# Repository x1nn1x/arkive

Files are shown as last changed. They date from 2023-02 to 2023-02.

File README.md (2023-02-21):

# Arkive v0.1 - 
Build your own Ark Dev Kit

A full Ark Dev Kit consists of a [screen](https://mou.sr/3QI0UAi), [battery](https://mou.sr/3QJygi1), [micro-sd card](https://mou.sr/3WlwoNI), [compute module](https://www.raspberrypi.com/products/compute-module-3-plus/), a case, and the Ark PCB both of which are available to be printed using this Arkive.

How To:

Upload one of these Gerber .zips to a PCB Manufacturer for them to print and deliver the PCBs needed you need to build an Ark Dev Kit. Print the case at home, or upload the files to a 3D printing service.

Notes:

Enabling touch screen

    Add Distro/pullup.dtbo to /boot/overlays
    Add Distro/touchscreen.dtbo to /boot/overlays
    Replace /home/pi/.bashrc with the Distro/.bashrc provided
    Make sure you are using the provided Distro/config.txt in /boot/

Enabling buttons

    Add Distro/buttons.dtbo to /boot/overlays
    Make sure you are using the provided Distro/config.txt in /boot/

Raspberry Pi Compute Module 3L+ (pending transition to CM4 and RISC-V): https://www.raspberrypi.com/products/compute-module-3-plus/

Newhaven Display 4.3" Capacitive Touch (pending transition to OLED and e-ink options]): [Mouser #: 763-4.3480272EFASXVC](https://mou.sr/3QI0UAi)

2500mAh LiPo battery: [Mouser #: 485-328](https://mou.sr/3QJygi1)

SD Card: [Mouser #: 467-SDSDQAD-128G](https://mou.sr/3WlwoNI)

Made with Love by Humans on Earth

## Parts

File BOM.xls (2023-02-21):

Sub-Assembly | Description | Part | Value | Package | Quantity | Link | Footprint Checked | Component
Pi Compute Module | SODIMM | A114854-ND | - | - | 1 | http://www.digikey.com/product-detail/en/te-connectivity-amp-connectors/1473149-4/A114854-ND/1890696 |  | U3
 | Resistor |  | 100k | 0402 | 5 | http://www.digikey.com/product-detail/en/panasonic-electronic-components/ERJ-2RKF1003X/P100KLCT-ND/194127 |  | R4, R5, R6, R7, R8
 | Capacitor |  | 4.7uF | 0603 | 2 | http://www.digikey.com/product-detail/en/samsung-electro-mechanics-america-inc/CL10B475KQ8NQNC/1276-2087-1-ND/3890173 |  | C2, C18
 | uSD Card Slot | WM6357CT-ND | - | - | 1 | http://www.digikey.com/product-detail/en/molex-llc/1040310811/WM6357CT-ND/2804769 |  | U4
 | Micro USB |  | - | - | 1 | http://www.digikey.com/product-detail/en/amphenol-fci/10103594-0001LF/609-4050-1-ND/2350357 |  | P2
Power Supplies | Fuse | MF-MSMF200-2CT-ND | 2A | - | 1 | http://www.digikey.com/product-detail/en/bourns-inc/MF-MSMF200-2/MF-MSMF200-2CT-ND/662850 |  | F1
 | Capacitor |  | 47uF | 1206 | 6 | http://www.digikey.com/product-detail/en/murata-electronics-north-america/GRM31CR60J476KE19L/490-6508-1-ND/3845705 |  | C1, C12, C14, C15, C16, C17
 | Capacitor |  | 100nF | 0402 | 2 | http://www.digikey.com/product-detail/en/kemet/C0402C104K9RACTU/399-4872-1-ND/1090867 |  | C5, C10
 | Capacitor |  | 10uF | 0805 | 4 | http://www.digikey.com/product-detail/en/murata-electronics-north-america/GRM219R60J106KE19D/490-3340-1-ND/702881 |  | C3, C4, C6, C7
 | Capacitor |  | 1uF | 0402 | 3 | http://www.digikey.com/product-detail/en/taiyo-yuden/JMK105BJ105KV-F/587-1231-1-ND/931008 |  | C9, C11, C13
 | Capacitor |  | 4.7uF | 0603 | 1 | http://www.digikey.com/product-detail/en/samsung-electro-mechanics-america-inc/CL10B475KQ8NQNC/1276-2087-1-ND/3890173 |  | C8
 | Resistor |  | 0R | 0402 | 2 | http://www.digikey.com/product-detail/en/panasonic-electronic-components/ERJ-2GE0R00X/P0.0JCT-ND/146726 |  | R1, R3
 | Resistor |  | 100k | 0402 | 1 | http://www.digikey.com/product-detail/en/panasonic-electronic-components/ERJ-2RKF1003X/P100KLCT-ND/194127 |  | R2
 | Inductor |  | 4.7uH 2A | - | 2 | http://www.digikey.com/product-detail/en/bourns-inc/SRN4018-4R7M/SRN4018-4R7MCT-ND/3821520 |  | L1, L2
 | Micro USB |  | - | - | 1 | http://www.digikey.com/product-detail/en/amphenol-fci/10103594-0001LF/609-4050-1-ND/2350357 |  | P1
 | 3v3 and 1v8 Regul | PAM2306AYPKE | - | - | 1 | http://www.mouser.com/ProductDetail/Diodes-Incorporated/PAM2306AYPKE/?qs=QK%2FAlAnD7r6vC0KF37wC2Q%3D%3D |  | U1
 | 2v5 Regul | AP7115-25SEG-7 | - | - | 1 | http://www.mouser.com/ProductDetail/Diodes-Incorporated/AP7115-25SEG-7/?qs=oUsD4qhOtFzl3uIiEMdYbQ%3D%3D |  | U2
Screen and Connector | LCD Screen |  | - | - | 1 |  |  | -
 | 40 Pin Connector | WM3431CT-ND | - | - | 1 | http://www.digikey.com/product-detail/en/molex-llc/0541044031/WM3431CT-ND/2405801 |  | P3
 | 6 Pin Connector |  | - | - | 1 |  |  | P4
 | Resistor Array |  | 33R | 1206 | 7 | http://www.digikey.com/product-detail/en/bourns-inc/CAY16-33R0F4LF/CAY16-33R0F4LFDKR-ND/5775070 |  | RP1 - RP7
 | Resistor |  | 10k | 0805 | 2 | http://www.digikey.com/product-detail/en/yageo/RC0805FR-0710KL/311-10.0KCRCT-ND/730482 |  | R9, R11
 | Resistor |  | 12R | 0805 | 1 | http://www.digikey.com/product-detail/en/yageo/RC0805FR-0712RL/311-12.0CRCT-ND/730514 |  | R10
 | Capacitor |  | 10uF | 0805 | 1 | http://www.digikey.com/product-detail/en/murata-electronics-north-america/GRM219R60J106KE19D/490-3340-1-ND/702881 |  | C21
 | Capacitor |  | 1uF | 0402 | 2 | http://www.digikey.com/product-detail/en/taiyo-yuden/JMK105BJ105KV-F/587-1231-1-ND/931008 |  | C19, C20
 | Capacitor |  | 100nF | 0402 | 1 | http://www.digikey.com/product-detail/en/kemet/C0402C104K9RACTU/399-4872-1-ND/1090867 |  | C22
 | Inductor | BRL3225T150K | - | - | 1 | http://www.digikey.com/product-detail/en/taiyo-yuden/BRL3225T150K/587-3027-1-ND/2763398 |  | L3
 | Diode | MBR0540 | - | - | 1 | http://www.digikey.com/product-detail/en/fairchild-on-semiconductor/MBR0540/MBR0540CT-ND/3042807 |  | D1
 | Diode | SMAZ24-TP | - | - | 1 | https://www.digikey.com/product-detail/en/micro-commercial-co/SMAZ24-TP/SMAZ24-TPMSCT-ND/1636198 |  | D2
 | LED Regul | FAN5333BSX | - | - | 1 | http://www.digikey.com/product-detail/en/fairchild-on-semiconductor/FAN5333BSX/FAN5333BSXCT-ND/3042778 |  | U5
Button Pad | Dome SW |  | - | - | 6 | https://www.digikey.com/product-detail/en/keystone-electronics/5133TR/36-5133CT-ND/6834345 |  | SW1 - SW6
 | Resistor |  | 10k | 0805 | 6 | http://www.digikey.com/product-detail/en/yageo/RC0805FR-0710KL/311-10.0KCRCT-ND/730482 |  | R12, R14, R16, R18, R20, R22
 | Resistor |  | 1k | 0805 | 6 | http://www.digikey.com/product-detail/en/yageo/RC0805FR-071KL/311-1.00KCRCT-ND/730391 |  | R13, R15, R17, R19, R21, R23
Battery Management | Charging Controller | MCP73871 | - | - | 1 | https://www.digikey.com/product-detail/en/microchip-technology/MCP73871-2CCI-ML/MCP73871-2CCI-ML-ND/1680971 |  | U7
 | Voltage Booster | TPS61090RSAR | - | - | 1 | https://www.digikey.com/product-detail/en/texas-instruments/TPS61090RSAR/296-15259-1-ND/566899 |  | U6
 | Capacitor |  | 10uF | 0805 | 2 | http://www.digikey.com/product-detail/en/murata-electronics-north-america/GRM219R60J106KE19D/490-3340-1-ND/702881 |  | C25, C27
 | Capacitor |  | 100nF | 0402 | 1 | http://www.digikey.com/product-detail/en/kemet/C0402C104K9RACTU/399-4872-1-ND/1090867 |  | C26
 | Capacitor |  | 2.2uF | 0603 | 1 | https://www.digikey.com/product-detail/en/yageo/CC0603KRX5R5BB225/311-1449-1-ND/2833755 |  | C23
 | Electrolytic Capacitor |  | 100uF | 1411 | 1 | https://www.digikey.com/product-detail/en/avx-corporation/F930J107KBA/478-8153-1-ND/4005595 |  | C24
 | Resistor |  | 1.87M | 0805 | 2 | https://www.digikey.com/product-detail/en/panasonic-electronic-components/ERJ-6ENF1874V/P1.87BTCT-ND/4429149 |  | R27, R31
 | Resistor |  | 340k | 0805 | 1 | https://www.digikey.com/product-detail/en/yageo/RC0805FR-07340KL/311-340KCRCT-ND/730822 |  | R32
 | Resistor |  | 200k | 0805 | 1 | https://www.digikey.com/product-detail/en/yageo/RC0805FR-07200KL/311-200KCRCT-ND/730671 |  | R30
 | Resistor |  | 1k | 0805 | 5 | http://www.digikey.com/product-detail/en/yageo/RC0805FR-071KL/311-1.00KCRCT-ND/730391 |  | R25, R28, R29, R34, R35
 | Resistor |  | 270k | 0805 | 1 | https://www.digikey.com/product-detail/en/yageo/RC0805FR-07270KL/311-270KCRCT-ND/730731 |  | R24
 | Resistor |  | 100k | 0402 | 2 | http://www.digikey.com/product-detail/en/panasonic-electronic-components/ERJ-2RKF1003X/P100KLCT-ND/194127 |  | R26, R36
 | Resistor |  | 15k | 0805 | 1 | https://www.digikey.com/product-detail/en/yageo/RC0805FR-0715KL/311-15.0KCRCT-ND/730555 |  | R33
 | Inductor | ASPI-0615FS-6R8M-T2 | 6.8uH | - | 1 | https://www.digikey.com/product-detail/en/abracon-llc/ASPI-0615FS-6R8M-T2/535-10777-1-ND/2619440 |  | L4
 | Transistor | MMUN2133LT1G | - | - | 1 | https://www.digikey.com/product-detail/en/on-semiconductor/MMUN2133LT1G/MMUN2133LT1GOSCT-ND/2705149 |  | Q1
 | Switch | MHSS1105 | SPDT | - | 1 | https://www.digikey.com/product-detail/en/apem-inc/MHSS1105/679-1849-ND/1949465 |  | U8
 | LED |  | - | 1206 | 4 | https://www.digikey.com/product-detail/en/lite-on-inc/LTST-C150GKT/160-1169-1-ND/269241 |  | D3 - D6
 | Battery Connector |  | - | - | 1 | https://www.digikey.com/product-detail/en/jst-sales-america-inc/S2B-PH-SM4-TB(LF)(SN)/455-1749-1-ND/926846 |  | BT1
 | Fuse | MF-MSMF200-2CT-ND | 2A | - | 1 | http://www.digikey.com/product-detail/en/bourns-inc/MF-MSMF200-2/MF-MSMF200-2CT-ND/662850 |  | F2
Total

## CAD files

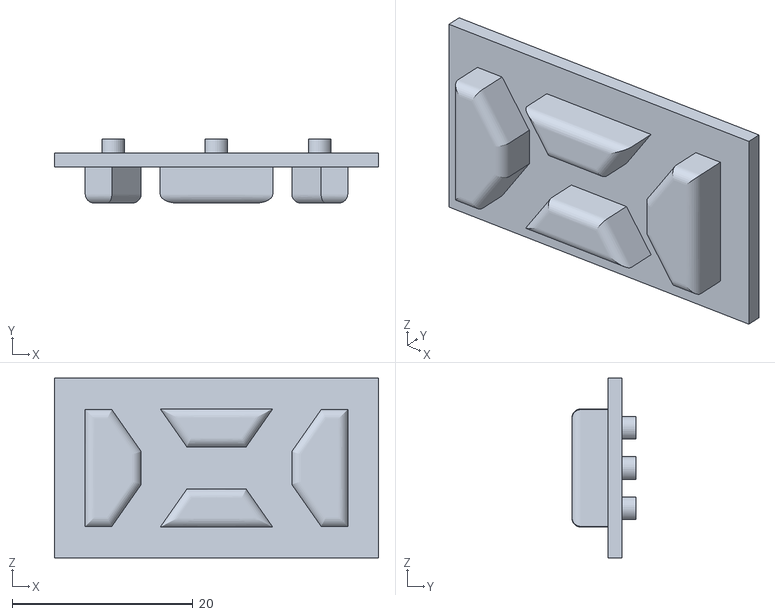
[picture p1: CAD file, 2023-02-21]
3D Printable Case 4inch snapclose/print-files/Button Arrows.stl
35.9 x 7.10 x 19.9

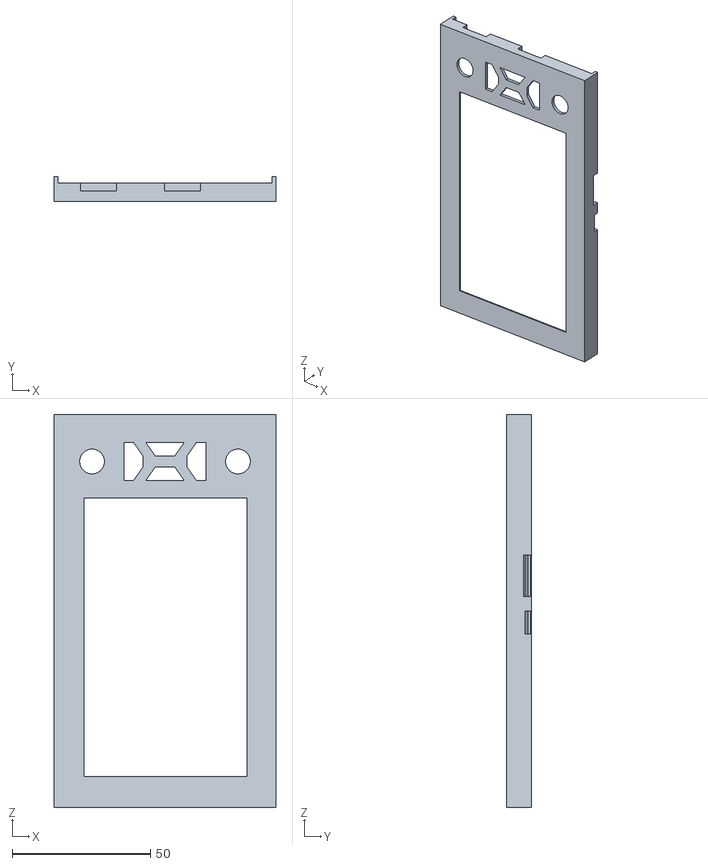
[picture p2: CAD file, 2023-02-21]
3D Printable Case 4inch snapclose/print-files/top-case.stl
80.3 x 9.22 x 142.3

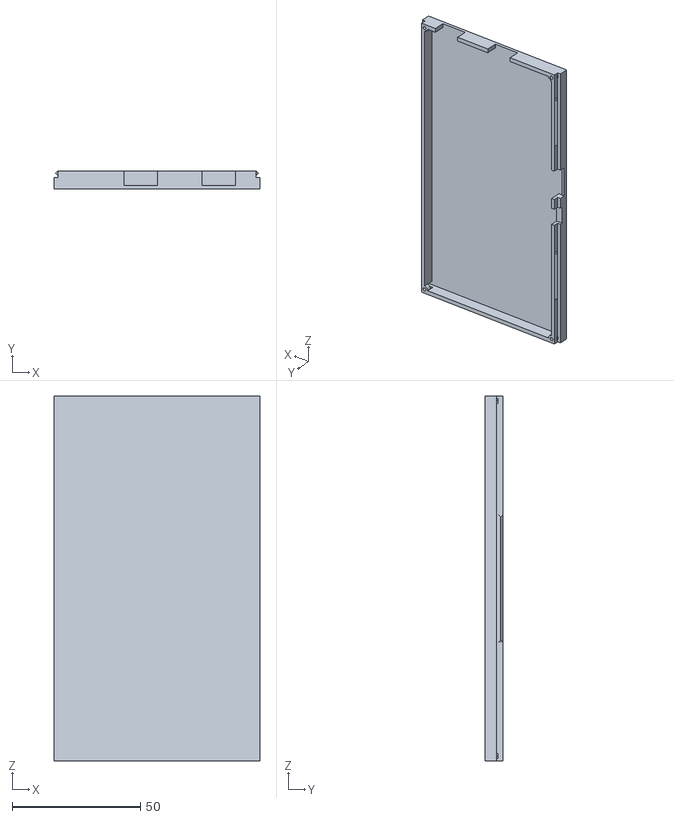
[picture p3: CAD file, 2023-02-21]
3D Printable Case 4inch snapclose/print-files/bottom-case.stl
80.3 x 7.13 x 142.3

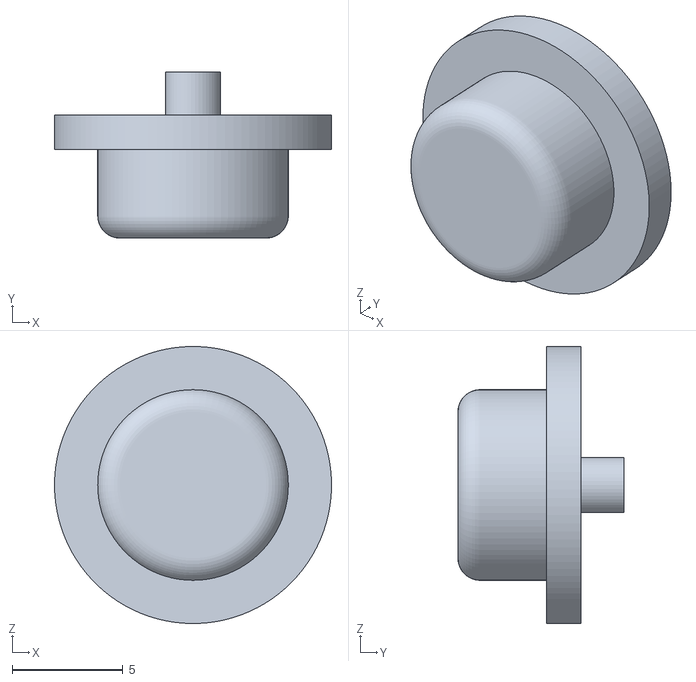
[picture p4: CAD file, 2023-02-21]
3D Printable Case 4inch snapclose/print-files/Button A.stl
12.5 x 7.50 x 12.5

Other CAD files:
3D Printable Case 4inch snapclose/print-files/Button B.stl
3D Printable Case 4inch snapclose/arkcase-snapclose.f3d

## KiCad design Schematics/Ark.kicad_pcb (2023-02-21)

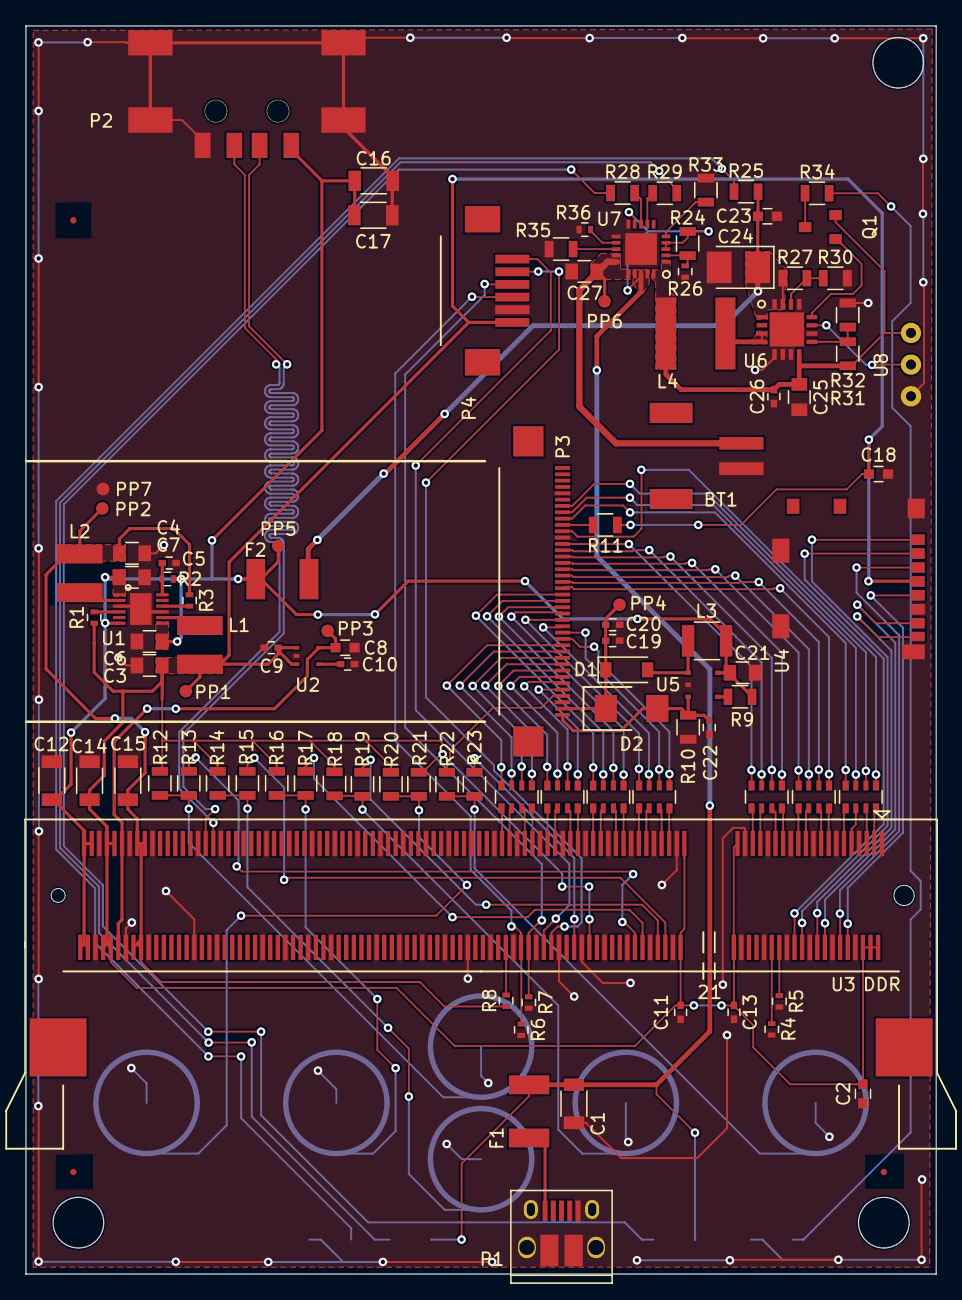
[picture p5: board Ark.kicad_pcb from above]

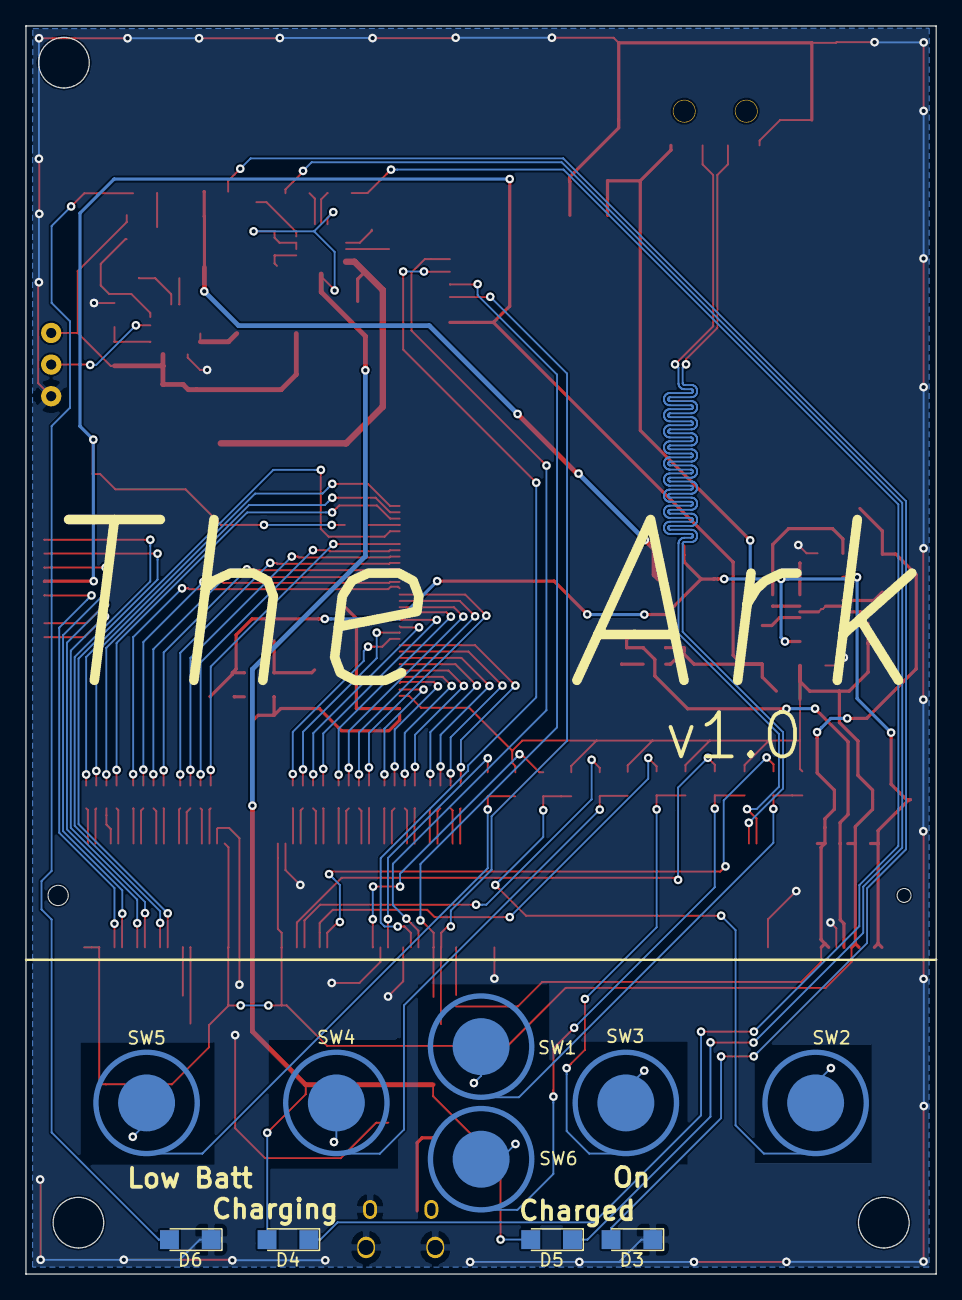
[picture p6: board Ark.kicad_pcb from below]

Board: 2 copper layers, 71.9 x 98.6 mm, 112 parts (10 on the bottom side), 120 nets.

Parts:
BT1: JST 2-PH; JST_2_PH
C1, C12, C14, C15, C16, C17: 47uF; C_1206
C2, C8, C18: 4.7uF; C_0603
C3, C4, C6, C7, C21, C25, C27: 10uF; C_0805
C5, C10, C22, C26: 100nF; C_0402
C9, C11, C13, C19, C20: 1uF; C_0402
C23: 2.2uF; C_0603
C24: 100uF; CP_Tantalum_Case-B_EIA-3528-21_Reflow
D1: MBR0540; D_SOD-123
D2: SMAZ24-TP
D3: Blue; LED_1206
D4: Orange; LED_1206
D5: Green; LED_1206
D6: Red; LED_1206
F1, F2: MF-MSMF200
L1, L2: 4.7uH; SRN4018-4R7M
L3: BRL3225T150K; C_1210
L4: 6.8uH; ASPI-0615FS-6R8M-T2
P1: USB_OTG; USB_Micro-B_10103594-0001LF
P2: USB_A; Wurth_USB_732-11179-1-ND
P3: 40_Pin_LCD_Out; LCD_Molex_Connector
P4: 6_Pin_Touch_In; Touch_Molex_Connector
P5, P6, P7: CONN_01X01; Fiducial
PP1, PP2, PP3, PP4, PP5, PP6, PP7: Test_Point
Q1: MMUN2133LT1G
R1, R3: 0R; R_0402
R2, R4, R5, R6, R7, R8, R26, R36: 100k; R_0402
R9, R11, R12, R14, R16, R18, R20, R22: 10k; R_0805
R10: 12; R_0805
R13, R15, R17, R19, R21, R23, R25, R28, R29, R34, R35: 1k; R_0805
R24: 270k; R_0805
R27, R31: 1.87M; R_0805
R30: 200k; R_0805
R32: 340k; R_0805
R33: 15k; R_0805
RP1, RP2, RP3, RP4, RP5, RP6, RP7: 33 R_PACK4; R_Array_Convex_4x0603
SW1, SW2, SW3, SW4, SW5, SW6: SW_PUSH_SMALL_H; Snapdome_SW
U1: PAM2306AYPKE
U2: AP7115-25SEG; AP7115-25SEG-7
U3: DDR2_SODIMM_CM_3_Lite; Socket_SODIMM_DDR2
U4: 1040310811; uSD_1040310811
U5: FAN5333BSX
U6: TPS61090RSAR
U7: MCP73871
U8: SPDT_switch; spdt_switch_MHSS1105

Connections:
1V8: C4.1, C15.1, L2.2, PP2.1, R3.1, R8.2, U3.183, U3.184, U3.185, U3.186
3V3: C2.1, C3.1, C9.1, C11.1, C13.1, C14.1, C18.1, L1.2, P3.4, P4.1, PP1.1, R1.1, R11.1, R12.2, R14.2, R16.2, R18.2, R20.2, R22.2, U2.1, U2.3, U3.2, U3.4, U3.6, U3.39, U3.40, U3.41, U3.42, U3.191, U3.192, U3.193, U3.194, U4.4
5V: C6.1, C7.1, C12.1, C16.1, C17.1, C21.1, F2.1, L3.1, P2.1, PP5.1, R2.1, R9.2, U1.1, U1.6, U1.7, U3.197, U3.198, U3.199, U3.200, U5.5
24V: C19.2, C20.2, D1.1, D2.1, P3.2, PP4.1
A: R21.2, U3.66
A_IN: R20.1, R21.1, SW2.1
B: R23.2, U3.70
B0: RP5.8, U3.15
B1: RP5.7, U3.17
B2: RP5.6, U3.21
B3: RP5.5, U3.23
B4: RP6.8, U3.27
B5: RP6.7, U3.29
B6: RP6.6, U3.33
B7: RP6.5, U3.35
B_IN: R22.1, R23.1, SW5.1
CM_VDAC: C8.1, PP3.1, U2.5, U3.189, U3.190
DE: RP7.7, U3.5
DOWN: R15.2, U3.46
DOWN_IN: R14.1, R15.1, SW6.1
EN_PWR: U6.11, U8.2
G0: RP3.8, U3.45
G1: RP3.7, U3.47
G2: RP3.6, U3.51
G3: RP3.5, U3.53
G4: RP4.8, U3.57
G5: RP4.7, U3.59
G6: RP4.6, U3.63
G7: RP4.5, U3.65
GND: BT1.2, C1.2, C2.2, C3.2, C4.2, C5.2, C6.2, C7.2, C8.2, C9.2, C10.2, C11.2, C12.2, C13.2, C14.2, C15.2, C16.2, C17.2, C18.2, C19.1, C20.1, C21.2, C22.2, C23.2, C24.2, C25.2, C26.2, C27.2, D3.1, D6.1, P1.5, P1.6, P2.4, P2.5, P3.3, P3.29, P3.36, P4.2, PP7.1, R4.2, R5.2, R6.2, R7.2, R10.1, R26.2, R30.2, R32.2, R33.2, R35.2, R36.2, SW1.2, SW2.2, SW3.2, SW4.2, SW5.2, SW6.2, U1.3, U1.9, U1.13, U2.2, U3.1, U3.7, U3.8, U3.13, U3.14, U3.19, U3.20, U3.25, U3.26, U3.31, U3.32, U3.37, U3.38, U3.43, U3.44, U3.49, U3.50, U3.55, U3.56, U3.61, U3.62, U3.67, U3.68, U3.73, U3.74, U3.79, U3.80, U3.85, U3.86, U3.91, U3.92, U3.97, U3.98, U3.103, U3.104, U3.109, U3.110, U3.115, U3.116, U3.121, U3.122, U3.127, U3.133, U3.134, U3.139, U3.140, U3.145, U3.146, U3.151, U3.152, U3.157, U3.163, U3.164, U3.169, U3.170, U3.181, U3.182, U3.187, U3.188, U3.195, U3.196, U4.6, U4.11, U4.12, U4.13, U4.14, U5.2, U6.5, U6.6, U6.7, U6.10, U6.13, U6.17, U7.10, U7.11, U7.21, U8.1
HSYNC: RP7.5, U3.11
INT: P4.5, U3.76
LEDK: C22.1, D2.2, P3.1, R10.2, U5.3
LEFT: R17.2, U3.52
LEFT_IN: R16.1, R17.1, SW3.1
unnamed: BT1.1, C27.1, PP6.1, U7.14, U7.15, U7.16
unnamed: C5.1, R2.2, U1.12
unnamed: C10.1, U2.4
unnamed: C23.1, C24.1, F2.2, R25.1, R27.1, U6.1, U6.15, U6.16
unnamed: D1.2, L3.2, U5.1
unnamed: D3.2, R25.2
unnamed: D4.1, R28.1
unnamed: D5.1, R29.1
unnamed: D6.2, R34.2
unnamed: F1.2, P1.1
unnamed: L1.1, U1.8
unnamed: L2.1, U1.2
unnamed: L4.2, U6.3, U6.4
unnamed: P3.5, RP1.1
unnamed: P3.6, RP1.2
unnamed: P3.7, RP1.3
unnamed: P3.8, RP1.4
unnamed: P3.9, RP2.1
unnamed: P3.10, RP2.2
unnamed: P3.11, RP2.3
unnamed: P3.12, RP2.4
unnamed: P3.13, RP3.1
unnamed: P3.14, RP3.2
unnamed: P3.15, RP3.3
unnamed: P3.16, RP3.4
unnamed: P3.17, RP4.1
unnamed: P3.18, RP4.2
unnamed: P3.19, RP4.3
unnamed: P3.20, RP4.4
unnamed: P3.21, RP5.1
unnamed: P3.22, RP5.2
unnamed: P3.23, RP5.3
unnamed: P3.24, RP5.4
unnamed: P3.25, RP6.1
unnamed: P3.26, RP6.2
unnamed: P3.27, RP6.3
unnamed: P3.28, RP6.4
unnamed: P3.30, RP7.1
unnamed: P3.31, R11.2
unnamed: P3.32, RP7.4
unnamed: P3.33, RP7.3
unnamed: P3.34, RP7.2
unnamed: Q1.1, U6.12
unnamed: Q1.3, R34.1
unnamed: R1.2, U1.4
unnamed: R3.2, U1.10
unnamed: R4.1, U3.30
unnamed: R5.1, U3.28
unnamed: R8.1, U3.88
unnamed: R9.1, U5.4
unnamed: R24.2, R26.1, U7.2
unnamed: R27.2, R30.1, U6.14
unnamed: R28.2, U7.8
unnamed: R29.2, U7.7
unnamed: R31.2, R32.1, U6.9
unnamed: R33.1, U7.5
unnamed: R35.1, U7.13
unnamed: R36.1, U7.12
ODCK: RP7.8, U3.3
PWR_IN: C1.1, D4.2, D5.2, F1.1, R24.1, U7.3, U7.4, U7.9, U7.17, U7.18, U7.19
R0: RP1.8, U3.69
R1: RP1.7, U3.71
R2: RP1.6, U3.75
R3: RP1.5, U3.77
R4: RP2.8, U3.81
R5: RP2.7, U3.83
R6: RP2.6, U3.87
R7: RP2.5, U3.89
RESET: P4.6, U3.78
RIGHT: R19.2, U3.48
RIGHT_IN: R18.1, R19.1, SW4.1
SCL: P4.3, R6.1, U3.84
SDA: P4.4, R7.1, U3.82
SDX_CLK: U3.10, U4.5
SDX_CMD: U3.12, U4.3
SDX_D0: U3.16, U4.7
SDX_D1: U3.18, U4.8
SDX_D2: U3.22, U4.1
SDX_D3: U3.24, U4.2
UP: R13.2, U3.54
UP_IN: R12.1, R13.1, SW1.1
USB_D+: P2.3, U3.165
USB_D-: P2.2, U3.167
VBAT: C25.1, C26.1, L4.1, Q1.2, R31.1, U6.8, U7.1, U7.20, U8.3
VSYNC: RP7.6, U3.9
